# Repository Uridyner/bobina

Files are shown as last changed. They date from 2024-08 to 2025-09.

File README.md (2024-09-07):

# Bobina/Bob 3.0
Holis a todos, estos son los códigos de Bobina (también conocida como Bob 3.0)

Símbolo electrónico de un inductor
Símbolo electrónico de un inductor
Símbolo electrónico de un inductor
Símbolo electrónico de un inductor
Símbolo electrónico de un inductor
Símbolo electrónico de un inductor
Símbolo electrónico de un inductor
Símbolo electrónico de un inductor
Símbolo electrónico de un inductor
Símbolo electrónico de un inductor
Símbolo electrónico de un inductor
Símbolo electrónico de un inductor
Símbolo electrónico de un inductor
Símbolo electrónico de un inductor
Símbolo electrónico de un inductor
Símbolo electrónico de un inductor

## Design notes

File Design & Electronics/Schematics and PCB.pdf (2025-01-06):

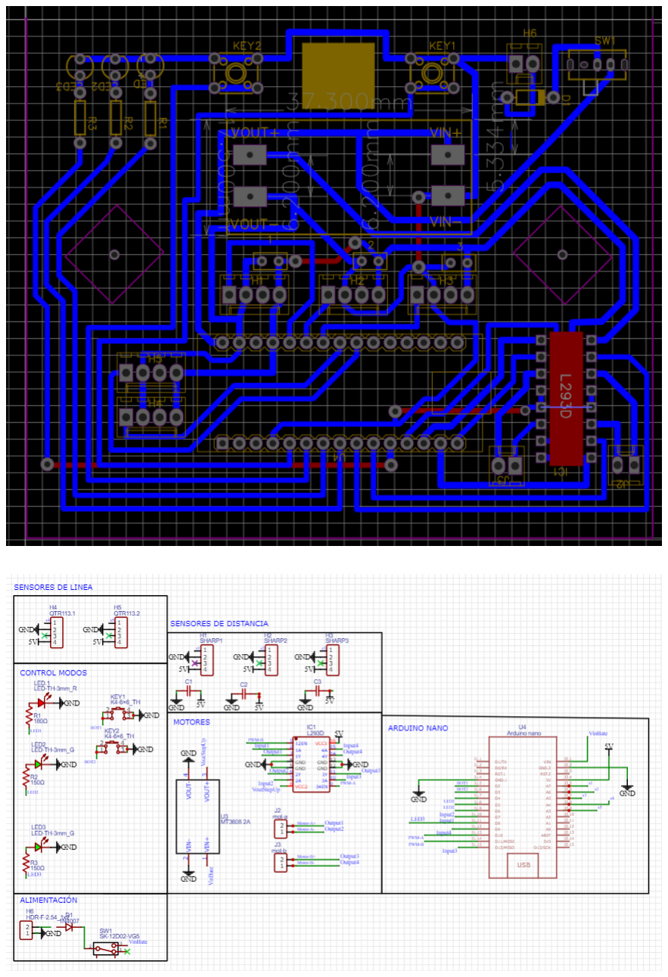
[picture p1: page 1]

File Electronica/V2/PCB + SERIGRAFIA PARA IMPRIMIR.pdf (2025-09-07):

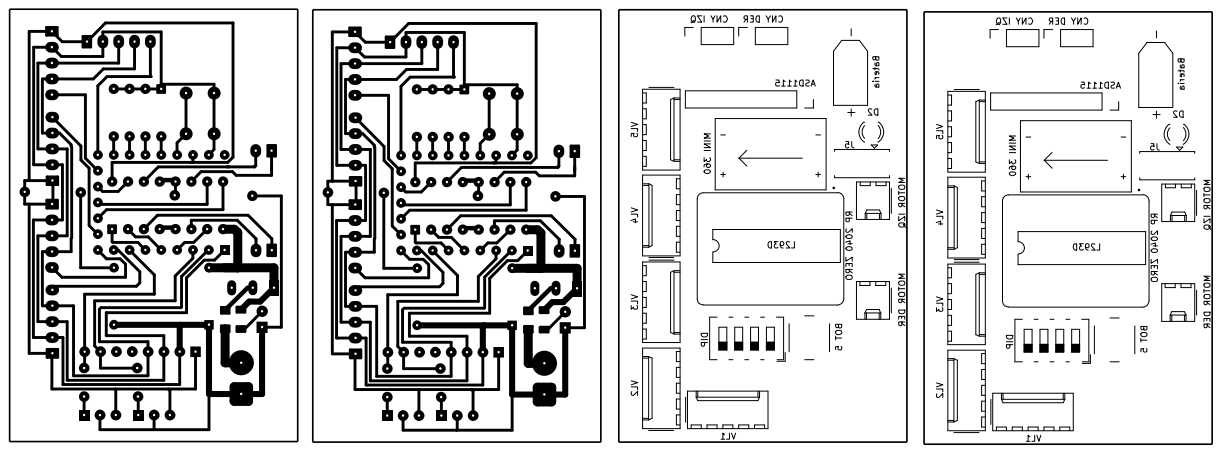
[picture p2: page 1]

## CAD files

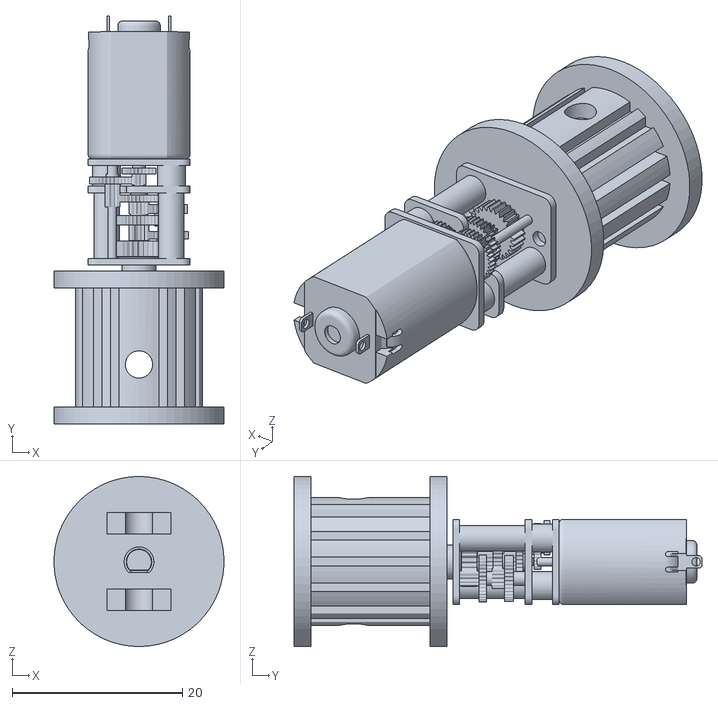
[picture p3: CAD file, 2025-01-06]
Design & Electronics/Wheel & Motor assembly.stl
20.0 x 48.0 x 20.0

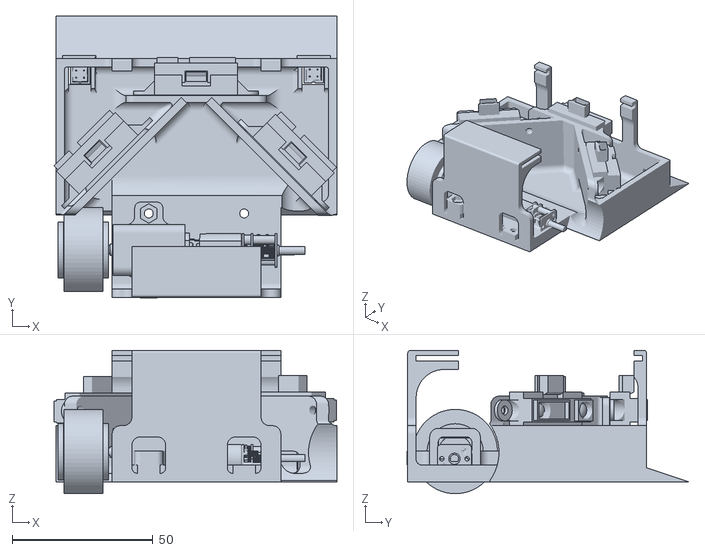
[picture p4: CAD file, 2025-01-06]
Design & Electronics/First bobina assembly.stl
100.7 x 100.2 x 51.0

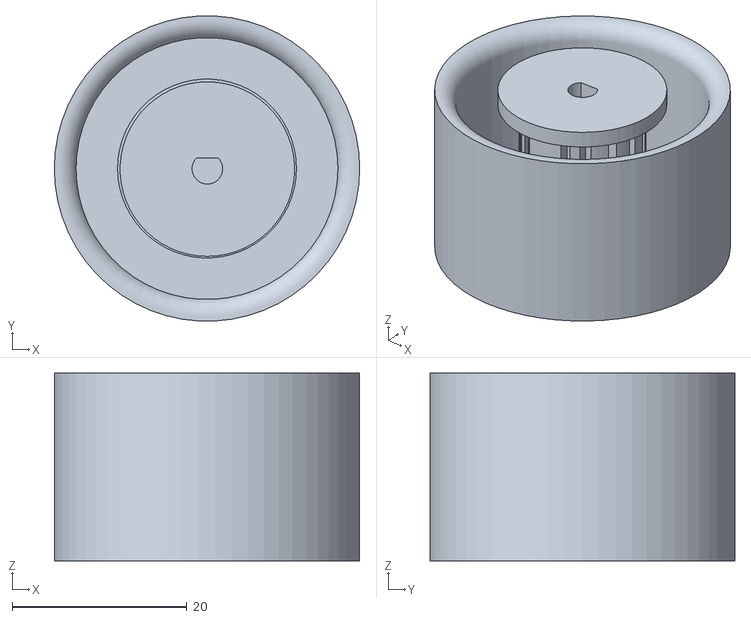
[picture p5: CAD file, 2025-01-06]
Design & Electronics/Mold & wheel assembly.stl
35.0 x 34.9 x 21.5

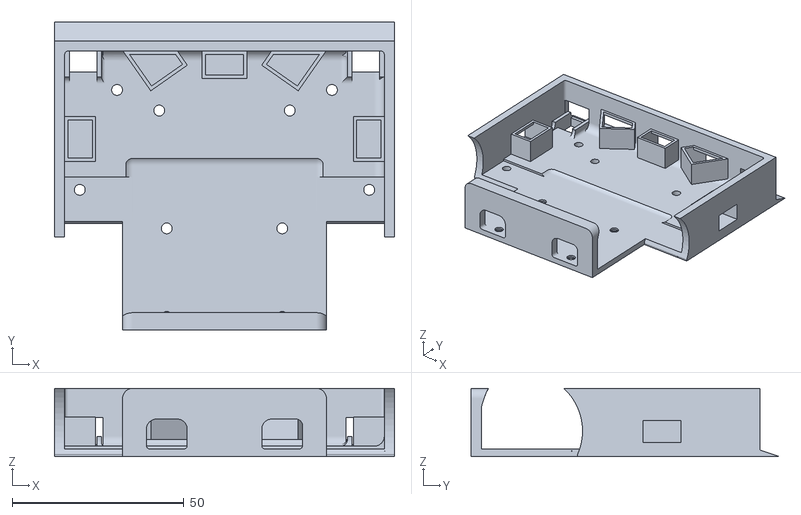
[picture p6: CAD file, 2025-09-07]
Design & Electronics/Nuevo Bobina V1.stl
99.0 x 89.6 x 19.8

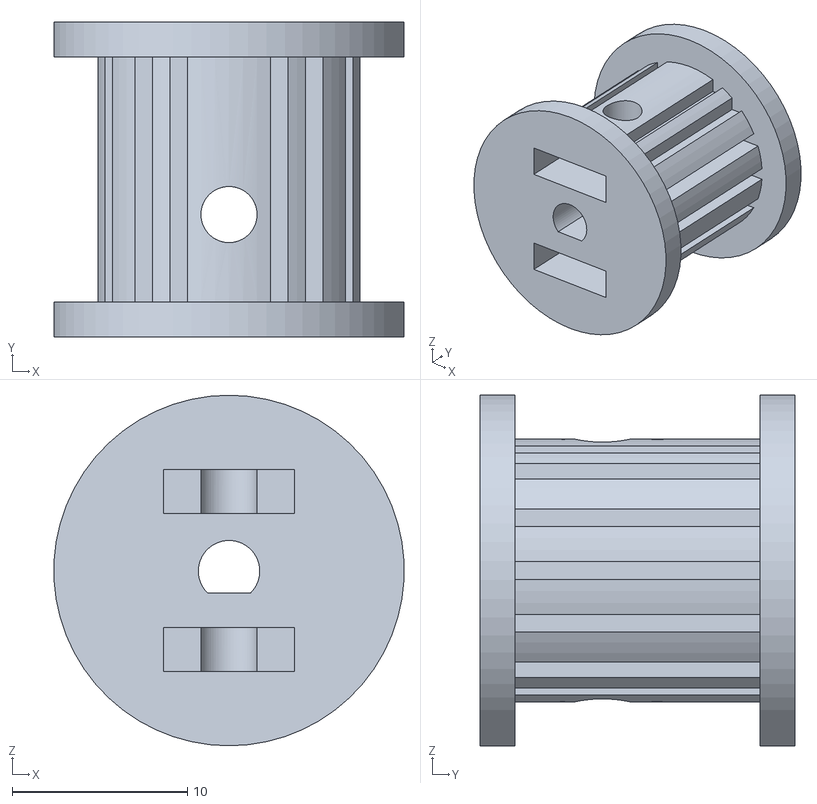
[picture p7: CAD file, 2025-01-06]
Design & Electronics/Wheel.stl
20.0 x 18.0 x 20.0

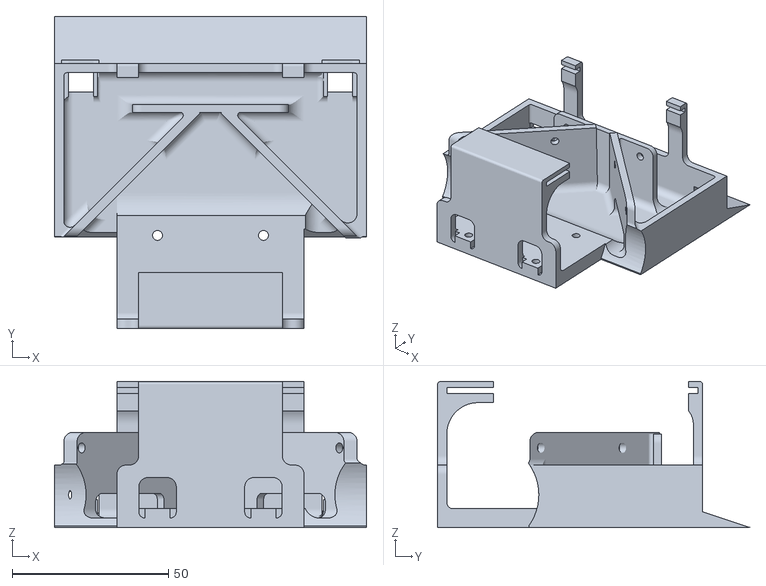
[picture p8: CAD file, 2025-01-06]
Design & Electronics/First Bobina.stl
100.0 x 100.0 x 46.8

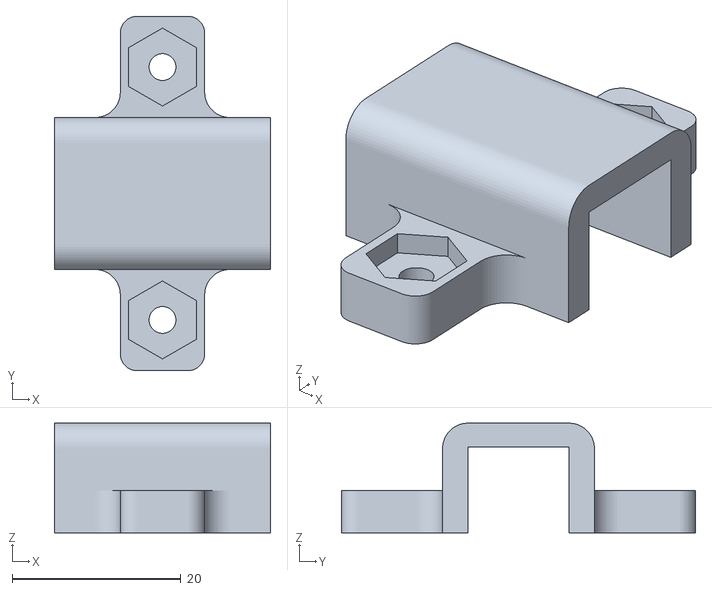
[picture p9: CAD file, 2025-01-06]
Design & Electronics/Motor holder.stl
25.6 x 42.0 x 13.0

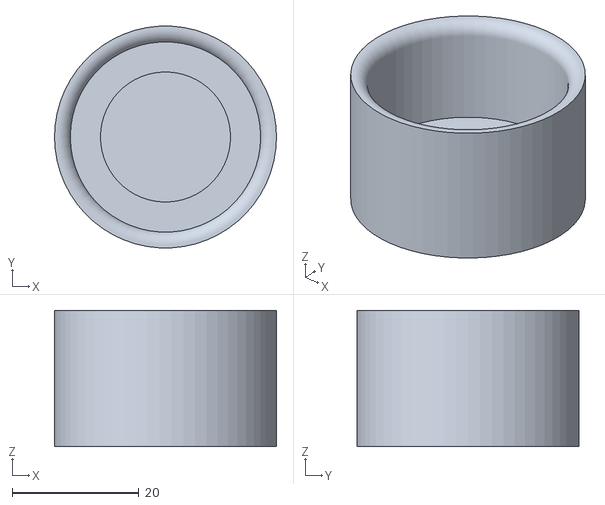
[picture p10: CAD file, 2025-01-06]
Design & Electronics/Mold.stl
35.0 x 34.9 x 21.5

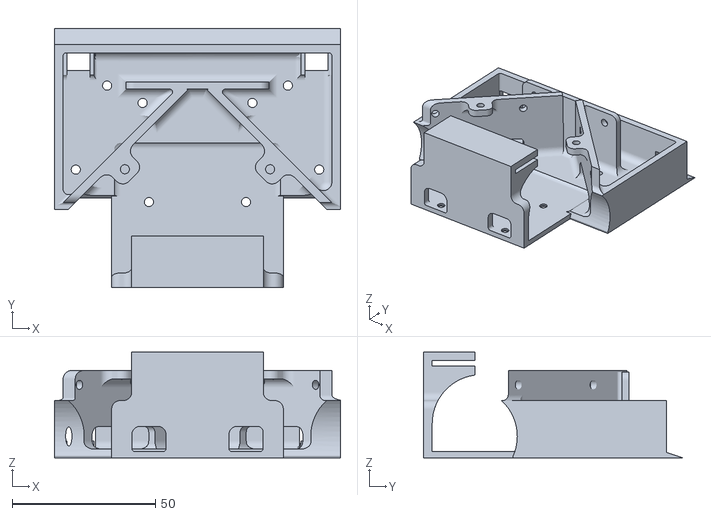
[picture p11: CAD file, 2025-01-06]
Design & Electronics/Last Bobina (for iron base).stl
100.0 x 90.5 x 37.0

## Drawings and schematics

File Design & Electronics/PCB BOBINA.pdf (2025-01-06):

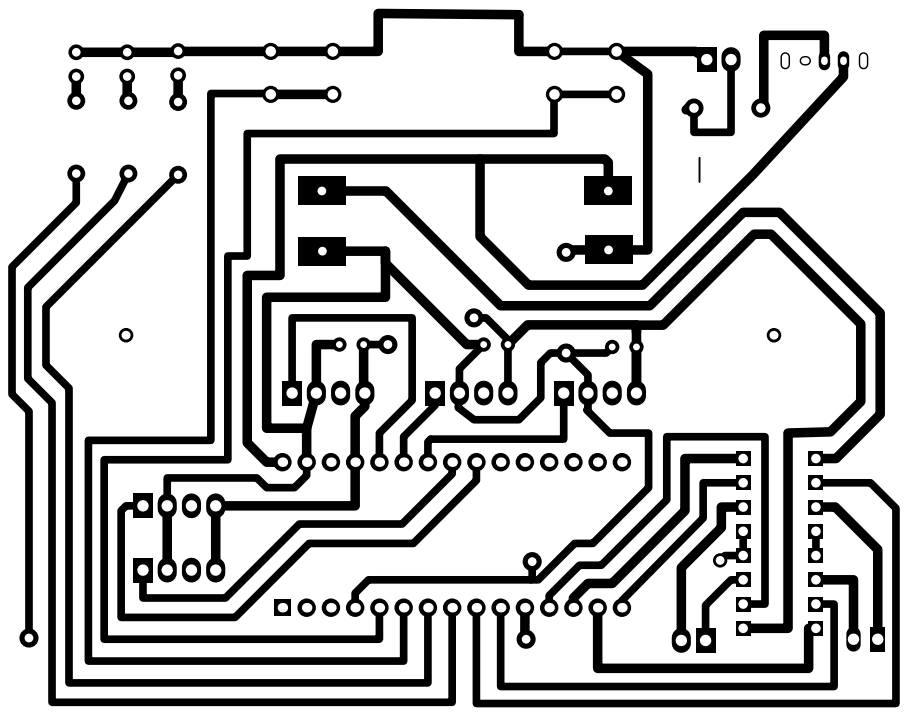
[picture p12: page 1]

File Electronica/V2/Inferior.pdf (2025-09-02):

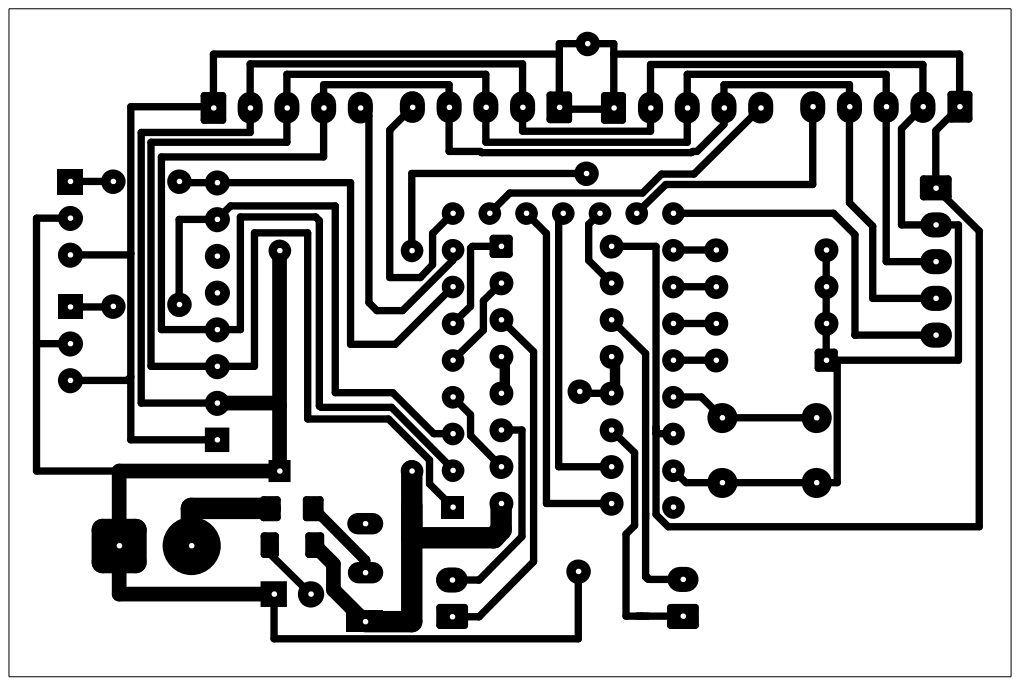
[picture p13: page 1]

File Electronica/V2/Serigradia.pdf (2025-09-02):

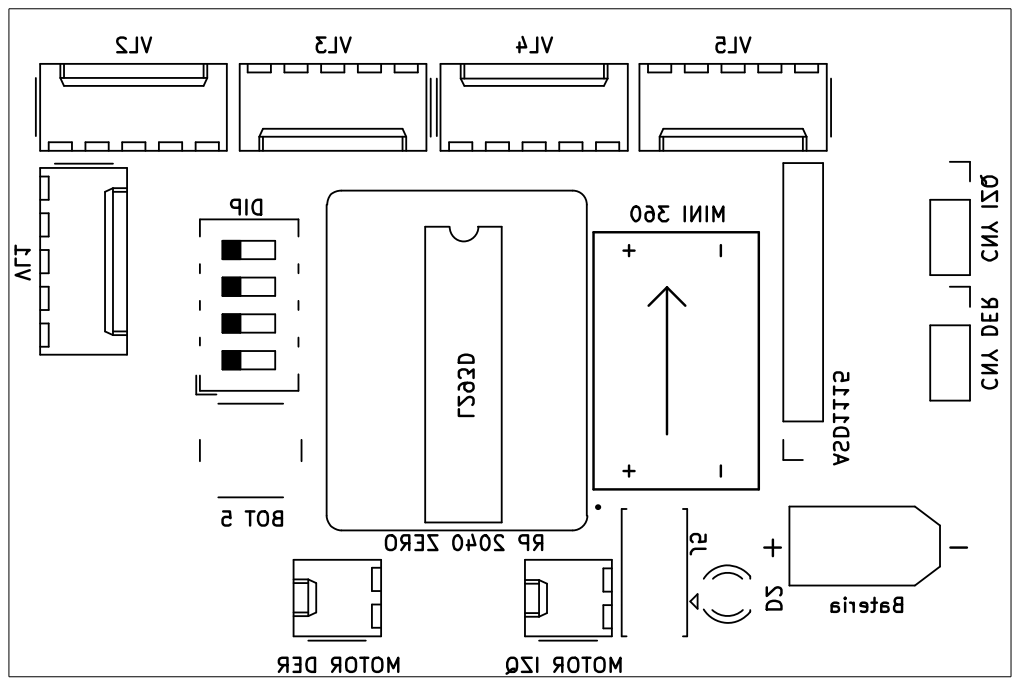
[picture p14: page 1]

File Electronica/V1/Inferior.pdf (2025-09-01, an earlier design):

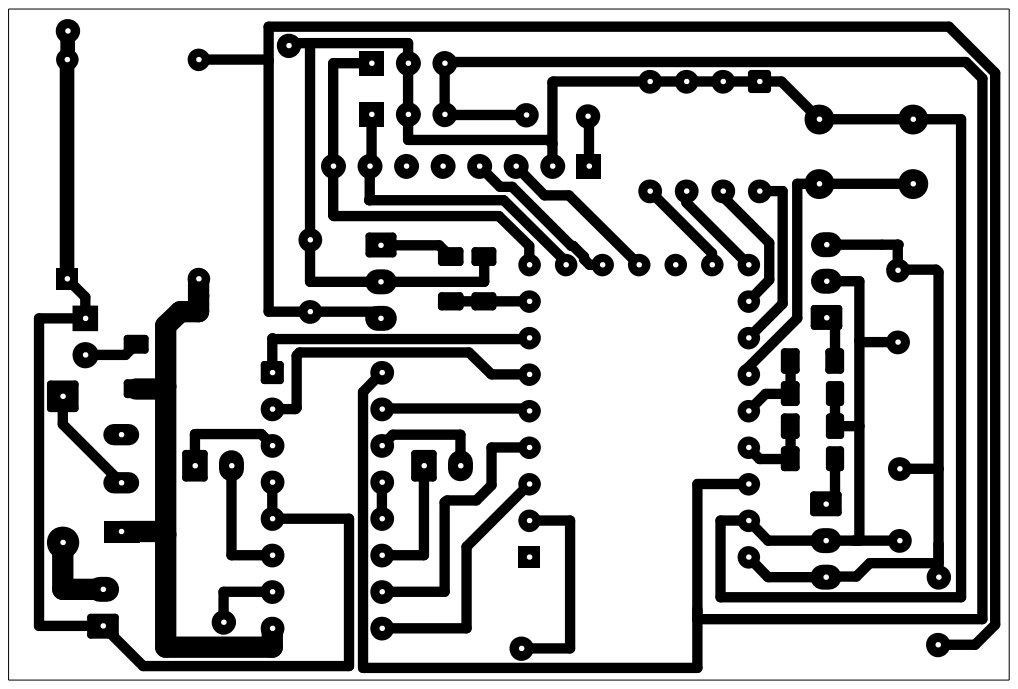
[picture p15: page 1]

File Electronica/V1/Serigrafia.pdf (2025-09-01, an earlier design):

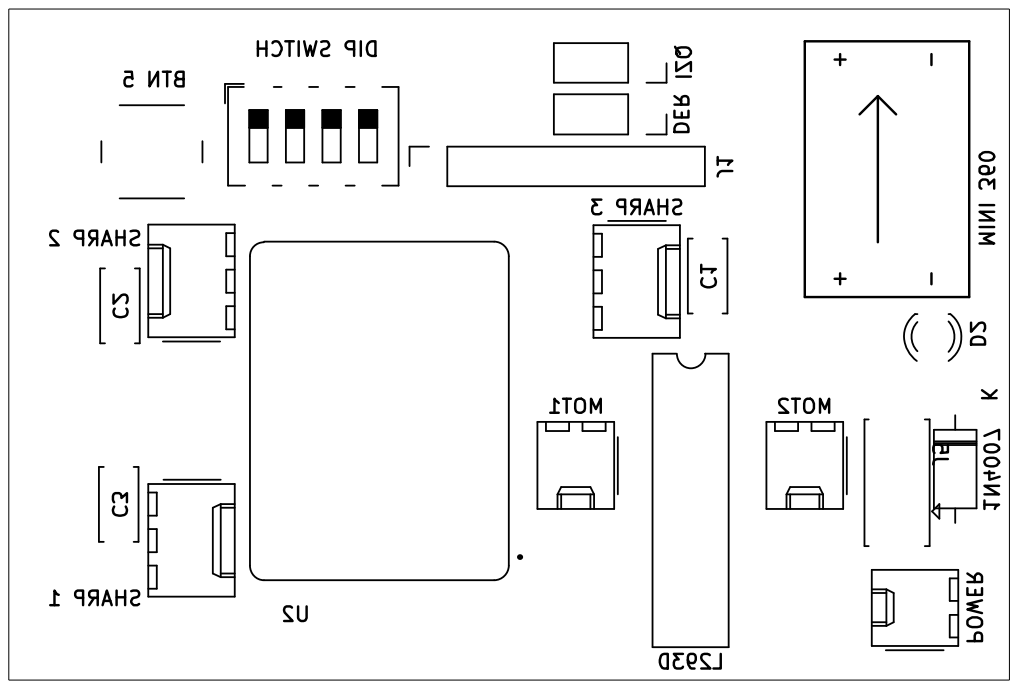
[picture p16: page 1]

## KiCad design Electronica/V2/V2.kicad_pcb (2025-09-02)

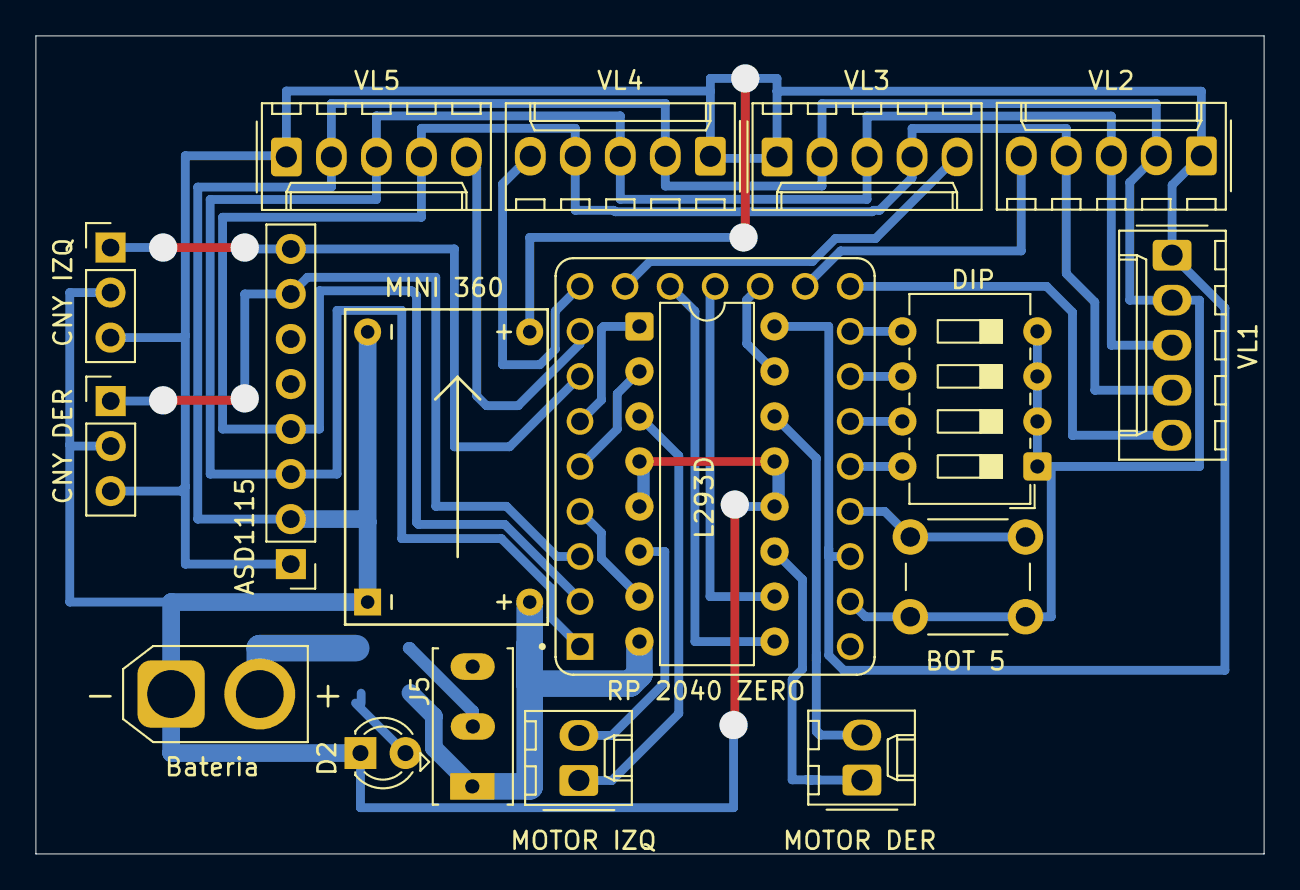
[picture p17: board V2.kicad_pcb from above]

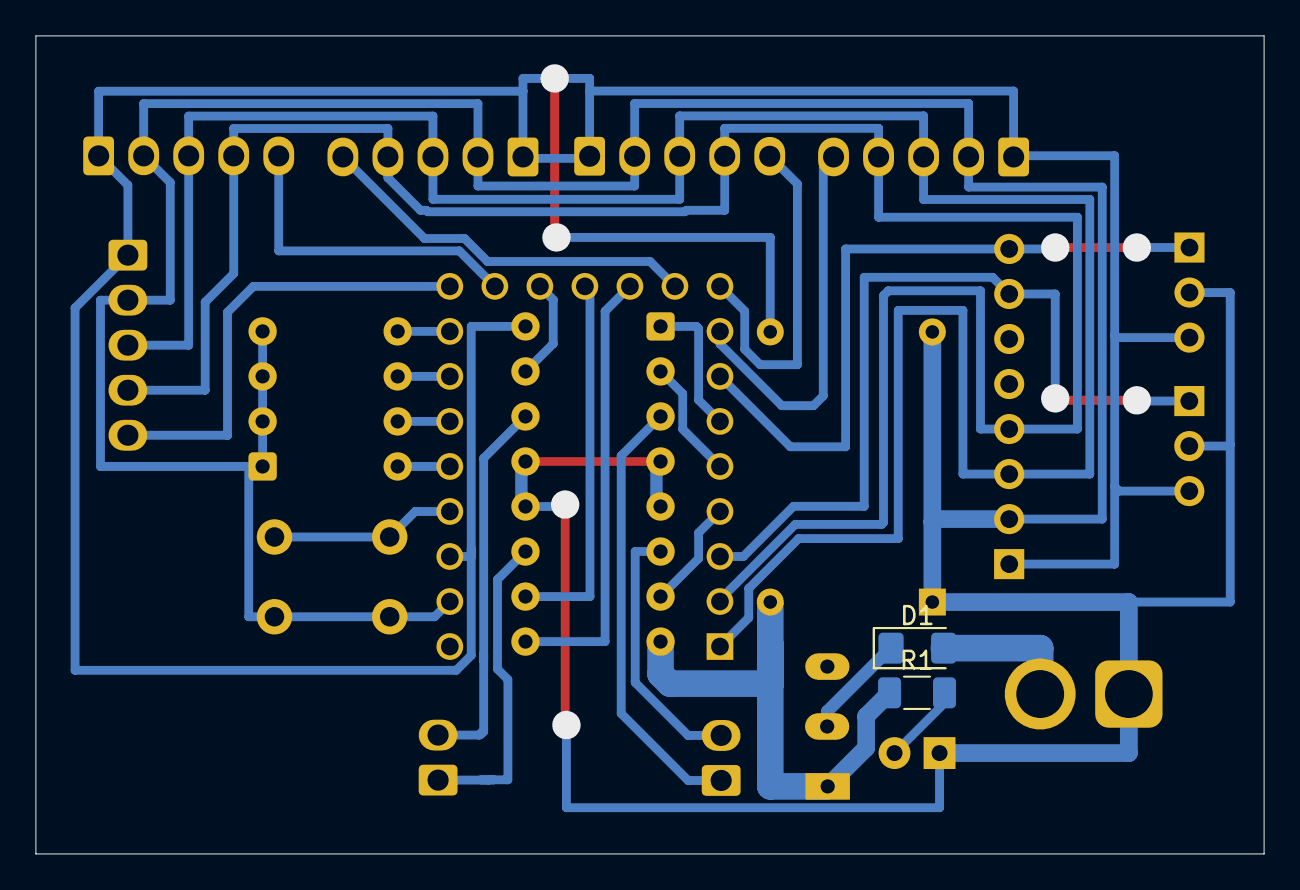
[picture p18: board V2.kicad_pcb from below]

Board: 2 copper layers, 69.3 x 46.2 mm, 20 parts (2 on the bottom side), 30 nets.

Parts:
ASD1115: Conn_01x08_Pin; PinHeader_1x08_P2.54mm_Vertical
BOT 5: SW_Push; SW_PUSH_6mm
Bateria: Power Input 1; AMASS_XT30U-F_1x02_P5.0mm_Vertical
CNY DER: Conn_01x03_Pin; PinHeader_1x03_P2.54mm_Vertical
CNY IZQ: Conn_01x03_Pin; PinHeader_1x03_P2.54mm_Vertical
D1: 1N4007; D_1206_3216Metric_Pad1.42x1.75mm_HandSolder
D2: LED; LED_D3.0mm_FlatTop
DIP: SW_DIP_x04; SW_DIP_SPSTx04_Slide_6.7x11.72mm_W7.62mm_P2.54mm_LowProfile
J5: On/Off General; SW_Slide_SPDT_Straight_CK_OS102011MS2Q
L293D: L293D; DIP-16_W7.62mm
MINI 360: Mini360_Module
MOTOR DER: Conn_01x02_Socket; Molex_KK-254_AE-6410-02A_1x02_P2.54mm_Vertical
MOTOR IZQ: Conn_01x02_Socket; Molex_KK-254_AE-6410-02A_1x02_P2.54mm_Vertical
R1: 220; R_1206_3216Metric_Pad1.30x1.75mm_HandSolder
RP 2040 ZERO: RP2040-ZERO; MODULE_RP2040-ZERO
VL1, VL2, VL3, VL4, VL5: Conn_01x05_Pin; Molex_KK-254_AE-6410-05A_1x05_P2.54mm_Vertical

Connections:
+3.3V: ASD1115.1, CNY DER.3, CNY IZQ.3, L293D.16 (VCC1), MINI 360.3 (OUT+), RP 2040 ZERO.21 (3V3), VL1.1, VL2.1, VL3.1, VL4.1, VL5.1
+12V: J5.1 (A), L293D.8 (VCC2), MINI 360.1 (IN+), R1.1
BOT1: DIP.8, RP 2040 ZERO.19 (GP28)
BOT2: DIP.7, RP 2040 ZERO.18 (GP27)
BOT3: DIP.6, RP 2040 ZERO.17 (GP26)
BOT4: DIP.5, RP 2040 ZERO.16 (GP15)
BOT5: BOT 5.2, RP 2040 ZERO.20 (GP29)
CNY_DER: ASD1115.7, CNY DER.1, RP 2040 ZERO.3 (GP2)
CNY_IZQ: ASD1115.8, CNY IZQ.1, RP 2040 ZERO.7 (GP6)
GND: ASD1115.2, BOT 5.1, Bateria.1, CNY DER.2, CNY IZQ.2, D2.1 (K), DIP.1, DIP.2, DIP.3, DIP.4, L293D.4 (GND), L293D.5 (GND), L293D.12 (GND), L293D.13 (GND), MINI 360.2 (IN-), MINI 360.4 (OUT-), RP 2040 ZERO.22 (GND), VL1.2, VL2.2, VL3.2, VL4.2, VL5.2
MOTORA1: L293D.2 (1A), RP 2040 ZERO.5 (GP4)
MOTORA2: L293D.7 (2A), RP 2040 ZERO.4 (GP3)
MOTORB1: L293D.10 (3A), RP 2040 ZERO.12 (GP11)
MOTORB2: L293D.15 (4A), RP 2040 ZERO.13 (GP12)
unnamed: Bateria.2, D1.2 (A)
unnamed: D1.1 (K), J5.2 (B)
unnamed: D2.2 (A), R1.2
unnamed: L293D.11 (3Y), MOTOR DER.1
unnamed: L293D.14 (4Y), MOTOR DER.2
unnamed: L293D.3 (1Y), MOTOR IZQ.1
unnamed: L293D.6 (2Y), MOTOR IZQ.2
PWMA: L293D.1 (EN1,2), RP 2040 ZERO.6 (GP5)
PWMB: L293D.9 (EN3,4), RP 2040 ZERO.11 (GP10)
SCL: ASD1115.3, RP 2040 ZERO.1 (GP0), VL1.3, VL2.3, VL3.3, VL4.3, VL5.3
SDA: ASD1115.4, RP 2040 ZERO.2 (GP1), VL1.4, VL2.4, VL3.4, VL4.4, VL5.4
VL1: RP 2040 ZERO.15 (GP14), VL1.5
VL2: RP 2040 ZERO.14 (GP13), VL2.5
VL3: RP 2040 ZERO.10 (GP9), VL3.5
VL4: RP 2040 ZERO.9 (GP8), VL4.5
VL5: RP 2040 ZERO.8 (GP7), VL5.5

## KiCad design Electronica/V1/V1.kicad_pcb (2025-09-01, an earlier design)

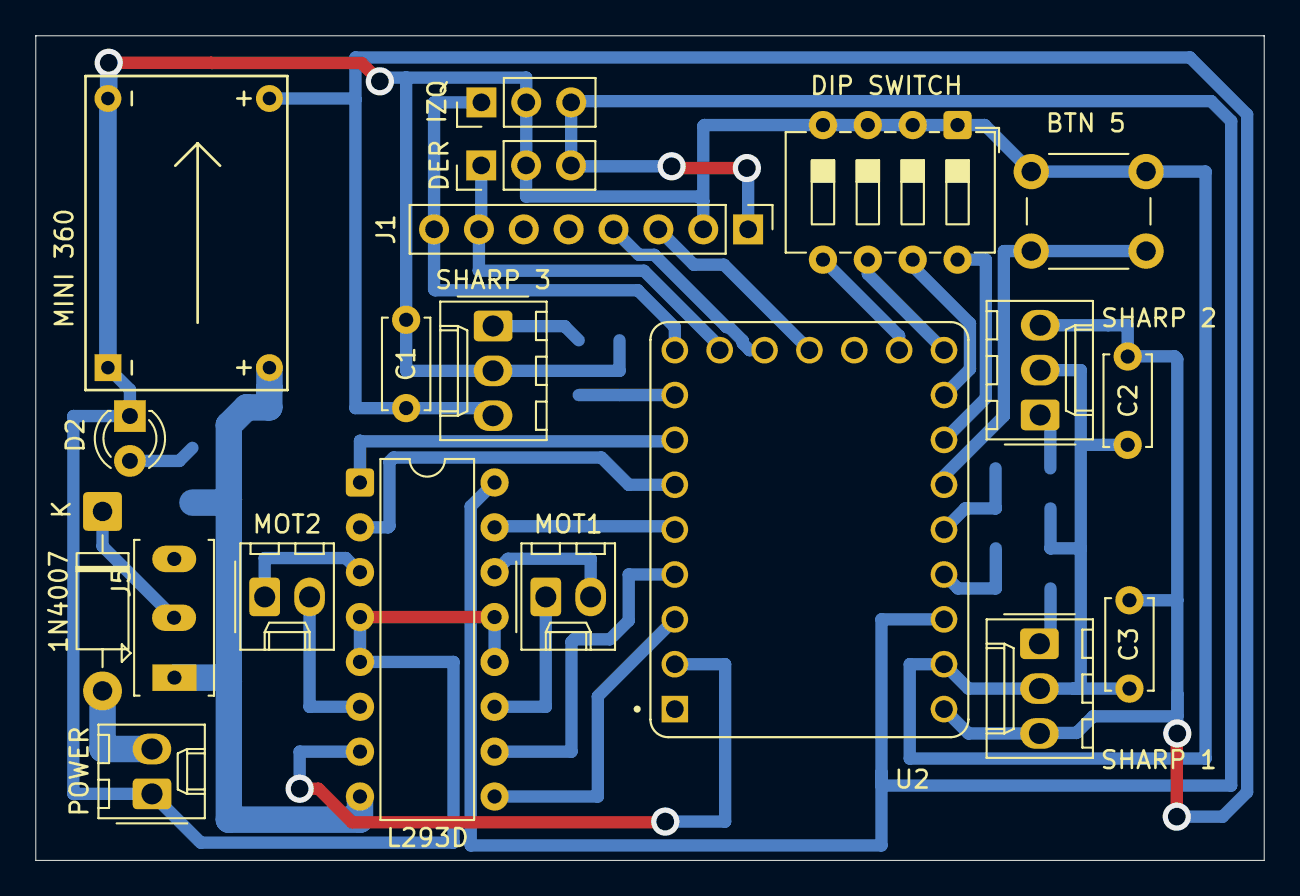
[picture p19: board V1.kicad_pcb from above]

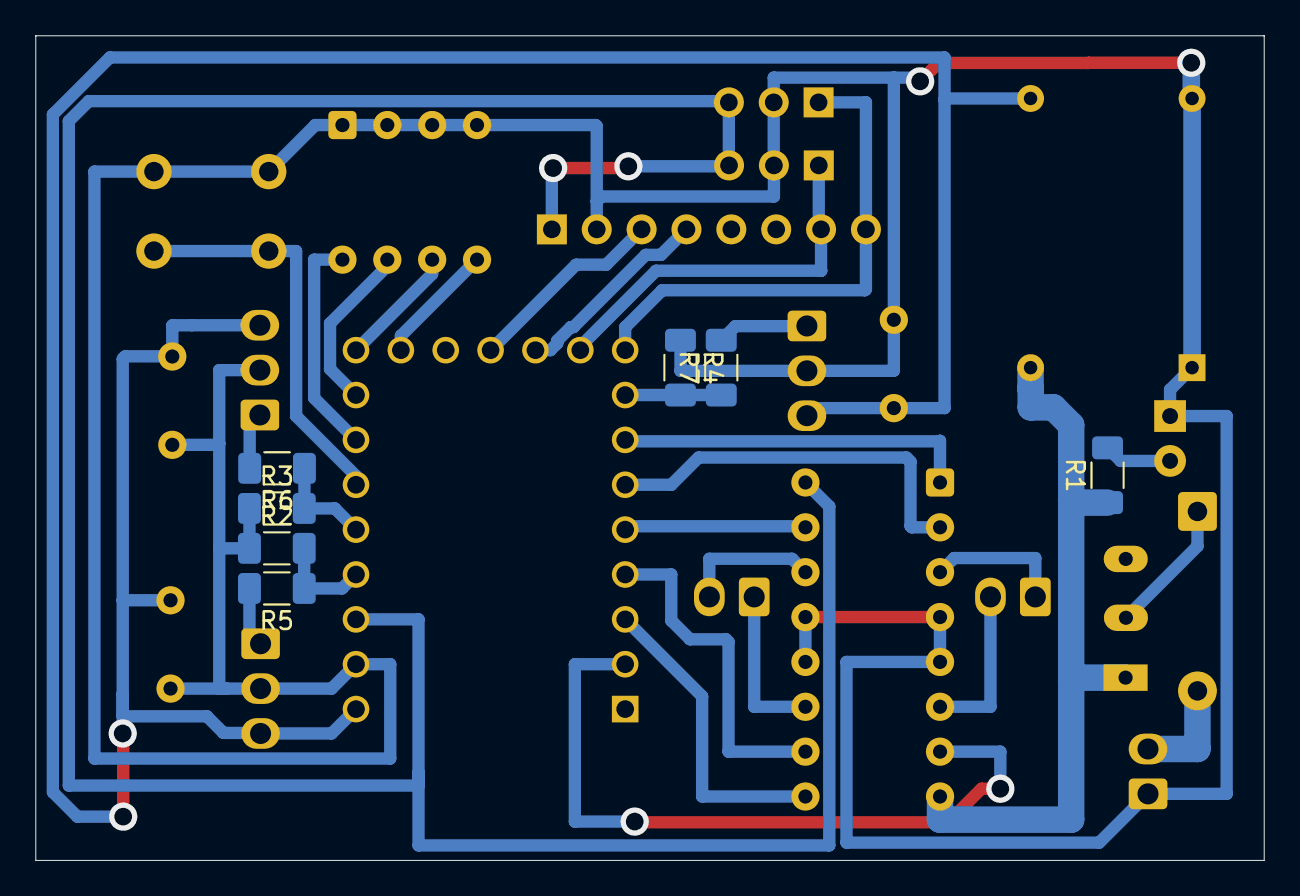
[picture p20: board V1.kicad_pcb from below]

Board: 2 copper layers, 69.6 x 46.7 mm, 27 parts (7 on the bottom side), 32 nets.

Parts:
1N4007: 1N4007; D_DO-41_SOD81_P10.16mm_Horizontal
BTN 5: SW_Push; SW_PUSH_6mm
C1, C2, C3: C_Small; C_Disc_D5.0mm_W2.5mm_P5.00mm
D2: LED; LED_D3.0mm_FlatTop
DER: Conn_01x03_Pin; PinHeader_1x03_P2.54mm_Vertical
DIP SWITCH: SW_DIP_x04; SW_DIP_SPSTx04_Slide_6.7x11.72mm_W7.62mm_P2.54mm_LowProfile
IZQ: Conn_01x03_Pin; PinHeader_1x03_P2.54mm_Vertical
J1: Conn_01x08_Pin; PinHeader_1x08_P2.54mm_Vertical
J5: On/Off General; SW_Slide_SPDT_Straight_CK_OS102011MS2Q
L293D: L293D; DIP-16_W7.62mm
MINI 360: Mini360_Module
MOT1, MOT2: Conn_01x02_Socket; Molex_KK-254_AE-6410-02A_1x02_P2.54mm_Vertical
POWER: Power Input 1; Molex_KK-254_AE-6410-02A_1x02_P2.54mm_Vertical
R1: 220; R_1206_3216Metric_Pad1.30x1.75mm_HandSolder
R2, R3, R4, R5, R6, R7: R; R_1206_3216Metric_Pad1.30x1.75mm_HandSolder
SHARP 1, SHARP 2, SHARP 3: Conn_01x03_Pin; Molex_KK-254_AE-6410-03A_1x03_P2.54mm_Vertical
U2: RP2040-ZERO; MODULE_RP2040-ZERO

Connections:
+3.3V: DER.3, IZQ.3, J1.1, L293D.16 (VCC1), U2.21 (3V3)
+5V: C1.2, C2.2, C3.2, MINI 360.3 (OUT+), SHARP 1.3, SHARP 2.3, SHARP 3.3, U2.23 (5V)
+12V: J5.1 (A), L293D.8 (VCC2), MINI 360.1 (IN+), R1.1
BOT1: DIP SWITCH.8, U2.17 (GP26)
BOT2: DIP SWITCH.7, U2.16 (GP15)
BOT3: DIP SWITCH.6, U2.15 (GP14)
BOT4: DIP SWITCH.5, U2.14 (GP13)
BOT5: BTN 5.2, U2.18 (GP27)
CNY_DER: DER.1, J1.7, U2.10 (GP9)
CNY_IZQ: IZQ.1, J1.8, U2.9 (GP8)
GND: BTN 5.1, C1.1, C2.1, C3.1, D2.1 (K), DER.2, DIP SWITCH.1, DIP SWITCH.2, DIP SWITCH.3, DIP SWITCH.4, IZQ.2, J1.2, L293D.4 (GND), L293D.5 (GND), L293D.12 (GND), L293D.13 (GND), MINI 360.2 (IN-), MINI 360.4 (OUT-), POWER.1, R2.1, R3.1, R4.1, SHARP 1.2, SHARP 2.2, SHARP 3.2, U2.22 (GND)
MOTORA1: L293D.2 (1A), U2.6 (GP5)
MOTORA2: L293D.7 (2A), U2.2 (GP1)
MOTORB1: L293D.10 (3A), U2.4 (GP3)
MOTORB2: L293D.15 (4A), U2.5 (GP4)
unnamed: 1N4007.2 (A), POWER.2
unnamed: 1N4007.1 (K), J5.2 (B)
unnamed: D2.2 (A), R1.2
unnamed: L293D.11 (3Y), MOT1.1
unnamed: L293D.14 (4Y), MOT1.2
unnamed: L293D.3 (1Y), MOT2.1
unnamed: L293D.6 (2Y), MOT2.2
PWMA: L293D.1 (EN1,2), U2.7 (GP6)
PWMB: L293D.9 (EN3,4), U2.3 (GP2)
Pin_Sharp_1: R2.2, R5.1, U2.20 (GP29)
Pin_Sharp_2: R3.2, R6.1, U2.19 (GP28)
Pin_Sharp_3: R4.2, R7.1, U2.8 (GP7)
SCL: J1.3, U2.12 (GP11)
SDA: J1.4, U2.11 (GP10)
Sharp1: R5.2, SHARP 1.1
Sharp2: R6.2, SHARP 2.1
Sharp3: R7.2, SHARP 3.1

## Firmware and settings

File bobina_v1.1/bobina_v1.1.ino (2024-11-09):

#include <Smoothed.h>

/// Motor izquierdo, adelante
constexpr uint8_t MOT_L_A = 7;
/// Motor izquierdo, atrás
constexpr uint8_t MOT_L_B = 6;
/// Motor izquierdo, velocidad/PWM
constexpr uint8_t MOT_L_PWM = 11;
/// Motor izquierdo, velocidad/PWM máximo
constexpr uint8_t MOT_L_PWM_MAX = 130;
/// Motor derecho, adelante
constexpr uint8_t MOT_R_A = 9;
/// Motor derecho, atrás
constexpr uint8_t MOT_R_B = 12;
/// Motor derecho, velocidad/PWM
constexpr uint8_t MOT_R_PWM = 10;
/// Motor derecho, velocidad/PWM máximo
constexpr uint8_t MOT_R_PWM_MAX = 130;

enum LadoSharp {
  SHARP_IZQ = 0,
  SHARP_CEN = 1,
  SHARP_DER = 2,
};
/// Pines de los sharps
constexpr uint8_t PINES_SHARPS[] = { A7, A6, A5 };
/// Numero de sharps en la placa
constexpr size_t NUM_SHARPS = sizeof(PINES_SHARPS) / sizeof(PINES_SHARPS[0]);
/// Cantidad de veces que se leen los sharps.
///
/// Se usa para tomar un promedio de las lecturas y limpiar los valores.
constexpr size_t LECTURAS_SHARP = 2;
/// Lecturas por segundos de los sharp
constexpr unsigned long FRECUENCIA_LECTURA_SHARP = 25;

enum LadoCNY {
  CNY_IZQ = 0,
  CNY_DER = 1,
};
/// Pines de los CNYs
constexpr uint8_t PINES_CNY[] = { A3, A4 };
/// Numero de CNYs en la placa
constexpr size_t NUM_CNY = sizeof(PINES_CNY) / sizeof(PINES_SHARPS[0]);
/// Cantidad de veces que se leen los CNYs.
///
/// Se usa para tomar un promedio de las lecturas y limpiar los valores.
constexpr size_t LECTURAS_CNY = 3;

/// Voltaje máximo del ADC
constexpr float VOLTAJE_MAX_ADC = 5.0;
/// Bits que tiene el ADC
constexpr uint8_t BITS_ADC = 10;
/// Valor máximo del ADC
constexpr uint16_t VALOR_MAX_ADC = 1024;
/// Convertir lectura a voltaje
constexpr float lecturaAVoltaje(uint16_t lectura) {
  return ((float)lectura * VOLTAJE_MAX_ADC) / (float)VALOR_MAX_ADC;
}
/// Convertir voltaje a lectura
constexpr uint16_t voltajeALectura(float voltaje) {
  return (uint16_t)((voltaje * (float)VALOR_MAX_ADC) / VOLTAJE_MAX_ADC);
}

/// Pines de los LEDs
constexpr uint8_t PINES_LEDS[] = { 8, 5, 4 };
/// Numero de LEDs en la placa
constexpr size_t NUM_LEDS = sizeof(PINES_LEDS) / sizeof(PINES_LEDS[0]);

/// Pines de los botones
constexpr uint8_t PINES_BOTONES[] = { 3, 2 };
/// Numero de botones en la placa
constexpr size_t NUM_BOTONES = sizeof(PINES_BOTONES) / sizeof(PINES_BOTONES[0]);

/// Tiempo que se espera antes de empezar a correr
constexpr unsigned int TIEMPO_ESPERA_MS = 5000;

/// Tiempo que retrocede cuando detecta que está sobre el borde
constexpr unsigned int TIEMPO_RETROCEDER_MS = 200;

/// Tiempo que se espera antes de avanzar forzadamente para evitar que se pare la pelea
constexpr unsigned int TIEMPO_ESPERA_AVANCE_FORZADO_MS = 500;

/// Tiempo que avanza forzadamente para evitar que se pare la pelea
constexpr unsigned int TIEMPO_AVANCE_FORZADO_MS = 350;

// #define DEBUG 1

#if DEBUG
#define debugSetup() Serial.begin(115200)
#define debugPrint(texto) Serial.print(texto)
#define debugPrintln(texto) Serial.println(texto)
#else
#define debugSetup()
#define debugSetup(baudios)
#define debugPrint(texto)
#define debugPrintln(texto)
#endif

void adelante() {
  debugPrintln("Adelante");
  digitalWrite(MOT_L_A, HIGH);
  digitalWrite(MOT_L_B, LOW);
  digitalWrite(MOT_R_A, HIGH);
  digitalWrite(MOT_R_B, LOW);
}

void atras() {
  debugPrintln("Atras");
  digitalWrite(MOT_L_A, LOW);
  digitalWrite(MOT_L_B, HIGH);
  digitalWrite(MOT_R_A, LOW);
  digitalWrite(MOT_R_B, HIGH);
}

void izquierda() {
  debugPrintln("Izquierda");
  digitalWrite(MOT_L_A, HIGH);
  digitalWrite(MOT_L_B, LOW);
  digitalWrite(MOT_R_A, LOW);
  digitalWrite(MOT_R_B, HIGH);
}

void derecha() {
  debugPrintln("Derecha");
  digitalWrite(MOT_L_A, LOW);
  digitalWrite(MOT_L_B, HIGH);
  digitalWrite(MOT_R_A, HIGH);
  digitalWrite(MOT_R_B, LOW);
}

void parada() {
  debugPrintln("Parada");
  digitalWrite(MOT_L_A, LOW);
  digitalWrite(MOT_L_B, LOW);
  digitalWrite(MOT_R_A, LOW);
  digitalWrite(MOT_R_B, LOW);
}

void frenar() {
  debugPrintln("Frenado");
  digitalWrite(MOT_L_A, HIGH);
  digitalWrite(MOT_L_B, HIGH);
  digitalWrite(MOT_R_A, HIGH);
  digitalWrite(MOT_R_B, HIGH);
}

void setupMotores() {
  debugPrintln("Inicializando pines de los motores...");
  debugPrintln("Pin motor izq adelante");
  pinMode(MOT_L_A, OUTPUT);
  debugPrintln("Pin motor izq atras");
  pinMode(MOT_L_B, OUTPUT);
  debugPrintln("Pin motor izq velocidad (PWM)");
  pinMode(MOT_L_PWM, OUTPUT);
  debugPrintln("Pin motor der adelante");
  pinMode(MOT_R_A, OUTPUT);
  debugPrintln("Pin motor der atras");
  pinMode(MOT_R_B, OUTPUT);
  debugPrintln("Pin motor der velocidad (PWM)");
  pinMode(MOT_R_PWM, OUTPUT);
  debugPrintln("Pines de los motores inicializados!");

  debugPrintln("Poniendo dirección inicial en los motores");
  frenar();
  debugPrintln("Puesta la dirección inicial en los motores!");

  debugPrintln("Poniendo velocidad en los motores");
  analogWrite(MOT_L_PWM, MOT_L_PWM_MAX);
  analogWrite(MOT_R_PWM, MOT_R_PWM_MAX);
  debugPrintln("Velocidad de los motores establecidas!");
}

unsigned long activacionesSharp[NUM_SHARPS] = { 55, 55, 55 };
Smoothed<uint16_t> smoothedSharps[NUM_SHARPS];
unsigned long ultimaLecturaSharps = -1;

Smoothed<uint16_t>* leerSharps() {
  if (millis() - ultimaLecturaSharps >= 1000 / FRECUENCIA_LECTURA_SHARP) {
    ultimaLecturaSharps = millis();
    for (size_t i = 0; i < NUM_SHARPS; i++) {
      uint16_t lectura = analogRead(PINES_SHARPS[i]);
      smoothedSharps[i].add(lectura);
      debugPrint("Sharp");
      debugPrint(i + 1);
      debugPrint(':');
      debugPrint(lectura);
      debugPrint('\t');
    }
    debugPrintln();
    ultimaLecturaSharps = millis();
  }
  return smoothedSharps;
}

void setupSharps() {
  debugPrintln("Inicializando pines de los sharps...");
  for (int i = 0; i < NUM_SHARPS; i++) {
    debugPrint("Sensor distancia sharp ");
    pinMode(PINES_SHARPS[i], INPUT);
    smoothedSharps[i].begin(SMOOTHED_AVERAGE, LECTURAS_SHARP);
    debugPrintln(i + 1);
  }
  debugPrintln("Pines de los sharps inicializados!");
}

float activacionesCNY[NUM_CNY] = { 0, 0 };
float lecturasCNY[NUM_CNY];

float* leerCNY() {
  for (size_t i = 0; i < NUM_CNY; i++) {
    lecturasCNY[i] = 0;
    for (size_t j = 0; j < LECTURAS_CNY; j++) {
      lecturasCNY[i] += lecturaAVoltaje(analogRead(PINES_CNY[i])) / LECTURAS_CNY;
    }
    debugPrint("CNY");
    debugPrint(i + 1);
    debugPrint(':');
    debugPrint(lecturasCNY[i]);
    debugPrint('\t');
  }
  debugPrintln();
  return lecturasCNY;
}

void setupCNY() {
  debugPrintln("Inicializando pines de los CNYs...");
  for (int i = 0; i < NUM_CNY; i++) {
    debugPrint("Sensor piso CNY ");
    pinMode(PINES_CNY[i], INPUT);
    debugPrintln(i + 1);
  }
  debugPrintln("Pines de los CNYs inicializados!");
}

void setupLeds() {
  debugPrintln("Inicializando pines de los leds...");
  for (int i = 0; i < NUM_LEDS; i++) {
    debugPrint("Led ");
    pinMode(PINES_LEDS[i], OUTPUT);
    debugPrintln(i + 1);
  }
  debugPrintln("Pines de los leds inicializados!");
}

inline void cambiarLed(size_t led, bool estado) {
  digitalWrite(PINES_LEDS[led], estado);
}

void setupBotones() {
  debugPrintln("Inicializando pines de los botones...");
  for (int i = 0; i < NUM_BOTONES; i++) {
    debugPrint("Boton ");
    pinMode(PINES_BOTONES[i], INPUT_PULLUP);
    debugPrintln(i + 1);
  }
  debugPrintln("Pines de los botones inicializados!");
}

inline bool estaPresionado(size_t boton) {
  bool valor = digitalRead(PINES_BOTONES[boton]);
  debugPrint("Boton ");
  debugPrint(boton);
  debugPrint(": ");
  debugPrintln(valor);
  return valor == LOW;
}

enum {
  BASICA_DER,
  BASICA_IZQ,
  PASITOS,
  // PRUEBA1,
  // PRUEBA2,
  // PRUEBA3,
  // PRUEBA4,
  // PRUEBA5,
  // PRUEBA6,
  // PRUEBA7,
  // PRUEBA8,
  // PRUEBA9,
  // PRUEBA10,
  // PRUEBA11,
  // PRUEBA12,
  // PRUEBA13,
  // PRUEBA14,
  // PRUEBA15,
  // PRUEBA16,
  // PRUEBA17,
  // PRUEBA18,
  // PRUEBA19,
  // PRUEBA20,
  // PRUEBA21,
  // PRUEBA22,
  // PRUEBA23,
  // PRUEBA24,
  NUM_ESTRATEGIAS,
} estrategia;

void setup() {
  debugSetup();

  for (size_t i = 0; i < NUM_LEDS - 1; i++) {
    cambiarLed(i, bitRead(0, i));
  }
  setupMotores();

  for (size_t i = 0; i < NUM_LEDS - 1; i++) {
    cambiarLed(i, bitRead(1, i));
  }
  setupSharps();

  for (size_t i = 0; i < NUM_LEDS - 1; i++) {
    cambiarLed(i, bitRead(2, i));
  }
  setupLeds();

  for (size_t i = 0; i < NUM_LEDS - 1; i++) {
    cambiarLed(i, bitRead(3, i));
  }
  setupCNY();

  for (size_t i = 0; i < NUM_LEDS - 1; i++) {
    cambiarLed(i, bitRead(4, i));
  }
  setupBotones();

  unsigned long ultimoCambioLeds = millis();
  unsigned long comienzoPresionBoton0 = millis();
  unsigned long comienzoPresionBoton1 = millis();
  bool ultimoEstadoBoton0 = estaPresionado(0);
  bool ultimoEstadoBoton1 = estaPresionado(1);

  while (true) {
    for (size_t i = 0; i < NUM_LEDS; i++) {
      unsigned char valor = (estrategia / (int)pow(3, NUM_LEDS - i - 1)) % 3;
      if (valor == 0) {
        cambiarLed(i, false);
      } else if (valor == 1) {
        cambiarLed(i, ((millis() + i * 100) % 400) < 100);
      } else if (valor == 2) {
        cambiarLed(i, true);
      }
    }
    bool estadoBoton0 = estaPresionado(0);
    bool estadoBoton1 = estaPresionado(1);
    if (estadoBoton0 == true && ultimoEstadoBoton0 == false) {
      comienzoPresionBoton0 = millis();
    } else if (estadoBoton0 == false && ultimoEstadoBoton0 == true && millis() - comienzoPresionBoton0 > 100) {
      estrategia = estrategia + 1;
      estrategia %= NUM_ESTRATEGIAS;
    }
    if (estadoBoton1 == true && ultimoEstadoBoton1 == false) {
      comienzoPresionBoton1 = millis();
    } else if (estadoBoton1 == false && ultimoEstadoBoton1 == true && millis() - comienzoPresionBoton1 > 100) {
      break;
    }
    ultimoEstadoBoton0 = estadoBoton0;
    ultimoEstadoBoton1 = estadoBoton1;
  }

  for (size_t i = 0; i < NUM_LEDS - 1; i++) {
    cambiarLed(i, true);
  }

  // Esperar a que se suelte
  while (estaPresionado(0) == false) {}

  // Esperar a que se aprete
  while (estaPresionado(1) == true) {}

  unsigned long tiempoComienzo = millis();

#if DEBUG
  unsigned char ultimoDigitoTiempoAnterior = -1;
#endif

  unsigned long ultimaLecturaCNYs = millis();
  unsigned int numeroLecturasCNYs = 1;
  unsigned long ultimaLecturaSharps = millis();
  unsigned int numeroLecturasSharps = 1;

  while (millis() - tiempoComienzo < TIEMPO_ESPERA_MS) {
    unsigned long segundosRestantes = (TIEMPO_ESPERA_MS - (millis() - tiempoComienzo)) / 1000;

    for (size_t i = 0; i < NUM_LEDS; i++) {
      cambiarLed(i, bitRead(segundosRestantes, i) == true);
    }

    if (millis() - ultimaLecturaCNYs > 20) {
      leerCNY();
      for (size_t i = 0; i < NUM_CNY; i++) {
        activacionesCNY[i] += lecturasCNY[i];
      }
      ultimaLecturaCNYs = millis();
      numeroLecturasCNYs++;
    }

    if (millis() - ultimaLecturaSharps > 40 && segundosRestantes <= 2) {
      for (size_t i = 0; i < NUM_SHARPS; i++) {
        unsigned long lectura = analogRead(PINES_SHARPS[i]);
        activacionesSharp[i] += lectura;
        debugPrint("Sharp");
        debugPrint(i + 1);
        debugPrint(':');
        debugPrint(lectura);
        debugPrint('\t');
      }
      debugPrintln();
      ultimaLecturaSharps = millis();
      numeroLecturasSharps++;
    }
  }

  debugPrintln("Activaciones CNYs");
  for (size_t i = 0; i < NUM_CNY; i++) {
    activacionesCNY[i] /= numeroLecturasCNYs;
    activacionesCNY[i] /= 2;
    debugPrint(activacionesCNY[i]);
    debugPrint('\t');
  }
  debugPrintln();

  debugPrintln("Activaciones Sharps");
  for (size_t i = 0; i < NUM_SHARPS; i++) {
    activacionesSharp[i] /= numeroLecturasSharps;
    activacionesSharp[i] *= 1.5;
    activacionesSharp[i] = constrain(activacionesSharp[i], 40, 70);
    debugPrint(activacionesSharp[i]);
    debugPrint('\t');
  }
  debugPrintln();

#if DEBUG
  delay(1000);
#endif
}

unsigned long ultimoRetroceso = -1;

unsigned long siguienteTiempoAvance = -1;

/// Literalmente solo buscar y matar
void estrategiaBasica(bool girarDerechaPorDefecto) {
  bool sharpIzq = smoothedSharps[SHARP_IZQ].get() > activacionesSharp[SHARP_IZQ];
  bool sharpCen = smoothedSharps[SHARP_CEN].get() > activacionesSharp[SHARP_CEN];
  bool sharpDer = smoothedSharps[SHARP_DER].get() > activacionesSharp[SHARP_DER];

  /// Último tiempo en milisegundos que empece a detectar algo en el sharp del centro
  static unsigned long ultimoTiempoDeteccionCentro = millis();
  /// Si la última vez que corrí detecté algo en el sharp del centro
  static bool ultimoDetectandoCentro = false;

  static bool avanzandoForzadamente = false;
  static unsigned long ultimoAvanceForzado = millis();
  if (millis() - ultimoAvanceForzado > TIEMPO_ESPERA_AVANCE_FORZADO_MS) {
    ultimoAvanceForzado = millis();
    avanzandoForzadamente = true;
  }
  if (avanzandoForzadamente) {
    if (millis() - ultimoAvanceForzado > TIEMPO_AVANCE_FORZADO_MS) {
      avanzandoForzadamente = false;
    }
    analogWrite(MOT_L_PWM, 255);
    analogWrite(MOT_R_PWM, 255);
    adelante();
  }

  if (sharpCen) {
    // Si acabo de detectar algo en el sharp del centro
    if (ultimoDetectandoCentro == false) {
      ultimoTiempoDeteccionCentro = millis();
    }
    if (millis() - ultimoTiempoDeteccionCentro > 300) {
      analogWrite(MOT_L_PWM, min((uint16_t)MOT_L_PWM_MAX + 50, 255));
      analogWrite(MOT_R_PWM, min((uint16_t)MOT_R_PWM_MAX + 50, 255));
    } else {
      analogWrite(MOT_L_PWM, min((uint16_t)MOT_L_PWM_MAX + 30, 255));
      analogWrite(MOT_R_PWM, min((uint16_t)MOT_R_PWM_MAX + 30, 255));
    }
    adelante();
  } else {
    analogWrite(MOT_L_PWM, MOT_L_PWM_MAX);
    analogWrite(MOT_R_PWM, MOT_R_PWM_MAX);
    if (girarDerechaPorDefecto) {
      if (sharpIzq) {
        izquierda();
      } else {
        derecha();
      }
    } else {
      if (sharpDer) {
        derecha();
      } else {
        izquierda();
      }
    }
  }

  ultimoDetectandoCentro = sharpCen;
}

void estrategiaPasitos() {
  bool sharpIzq = smoothedSharps[SHARP_IZQ].get() > activacionesSharp[SHARP_IZQ];
  bool sharpCen = smoothedSharps[SHARP_CEN].get() > activacionesSharp[SHARP_CEN];
  bool sharpDer = smoothedSharps[SHARP_DER].get() > activacionesSharp[SHARP_DER];
}

unsigned long comienzoRetroceso = millis();
bool retrocediendo = false;

void loop() {
  leerSharps();
  debugPrint(activacionesSharp[SHARP_IZQ]);
  debugPrint('\t');
  debugPrint(activacionesSharp[SHARP_CEN]);
  debugPrint('\t');
  debugPrintln(activacionesSharp[SHARP_DER]);

  leerCNY();
  debugPrint(lecturasCNY[CNY_IZQ]);
  debugPrint('\t');
  debugPrintln(lecturasCNY[CNY_DER]);

  bool cnyIzq = lecturasCNY[CNY_IZQ] <= activacionesCNY[CNY_IZQ];
  bool cnyDer = lecturasCNY[CNY_DER] <= activacionesCNY[CNY_DER];
  if (cnyIzq || cnyDer) {
    if (millis() - comienzoRetroceso <= TIEMPO_RETROCEDER_MS * 2) {
      comienzoRetroceso = millis() - TIEMPO_RETROCEDER_MS / 2;
    } else {
      comienzoRetroceso = millis();
    }
    retrocediendo = true;
  }

  if (retrocediendo) {
    if (millis() - comienzoRetroceso > TIEMPO_RETROCEDER_MS) {
      retrocediendo = false;
    }
    analogWrite(MOT_L_PWM, MOT_L_PWM_MAX);
    analogWrite(MOT_R_PWM, MOT_R_PWM_MAX);
    atras();
  } else {
    switch (estrategia) {
      case BASICA_DER:
        estrategiaBasica(false);
        break;
      case BASICA_IZQ:
        estrategiaBasica(true);
        break;
      case PASITOS:
        estrategiaBasica(true);
        break;
    }
  }

  bool sharpIzq = smoothedSharps[SHARP_IZQ].get() > activacionesSharp[SHARP_IZQ];
  bool sharpCen = smoothedSharps[SHARP_CEN].get() > activacionesSharp[SHARP_CEN];
  bool sharpDer = smoothedSharps[SHARP_DER].get() > activacionesSharp[SHARP_DER];

  cambiarLed(0, sharpIzq);
  cambiarLed(1, sharpCen);
  cambiarLed(2, sharpDer);
  // for (size_t i = 0; i < NUM_LEDS; i++) {
  //   cambiarLed(i, bitRead(smoothedSharps[SHARP_CEN].get() >> 1, i) == true);
  // }
#if DEBUG
  delay(100);
#endif
}

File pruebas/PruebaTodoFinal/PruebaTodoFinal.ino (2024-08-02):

#include "TimerOne.h"


#define BOTON_1 2
#define BOTON_2 3

#define LED_V 4
#define LED_R1 5
#define LED_R2 8


#define INIT 0
#define E1 1
#define E2 2
#define START 3
#define E3 4
#define E4 5
#define E5 6


int estadob1 = 0;
int estadob2 = 0;
int mseg = 0;
int estadoLogica = 0;

#define ESPERA 0
#define CONFIRMACION 1
#define LIBERACION 2

#define TIEMPO_antiReboteBoton1 15
int estadoantiReboteBoton1 = 0;
int mSegantiReboteBoton1 = 0;
int flagBoton1 = 0;

#define TIEMPO_antiReboteBoton2 15
int estadoantiReboteBoton2 = 0;
int mSegantiReboteBoton2 = 0;
int flagBoton2 = 0;

int flagEstrategia = 0;

#define CNY1 A6
#define CNY2 A4
int valorCNY1 = 0;
int valorCNY2 = 0;

//MOTORES y SHARPS
constexpr uint8_t MOT_L_A = 7;
constexpr uint8_t MOT_L_B = 6;
constexpr uint8_t MOT_L_PWM = 11;
constexpr uint8_t MOT_R_A = 9;
constexpr uint8_t MOT_R_B = 12;
constexpr uint8_t MOT_R_PWM = 10;

constexpr uint8_t PINES_SHARPS[3] = { A7, A5, A3 };
constexpr size_t NUM_SHARPS = sizeof(PINES_SHARPS) / sizeof(PINES_SHARPS[0]);

constexpr float VOLTAJE_MAX_ADC = 5.0;
constexpr uint8_t BITS_ADC = 10;
constexpr uint16_t VALOR_MAX_ADC = pow(2, BITS_ADC);

void adelante() {
  Serial.println("Adelante");
  digitalWrite(MOT_L_A, HIGH);
  digitalWrite(MOT_L_B, LOW);
  digitalWrite(MOT_R_A, HIGH);
  digitalWrite(MOT_R_B, LOW);
}

void atras() {
  Serial.println("Atras");
  digitalWrite(MOT_L_A, LOW);
  digitalWrite(MOT_L_B, HIGH);
  digitalWrite(MOT_R_A, LOW);
  digitalWrite(MOT_R_B, HIGH);
}

void izquierda() {
  Serial.println("Izquierda");
  digitalWrite(MOT_L_A, HIGH);
  digitalWrite(MOT_L_B, LOW);
  digitalWrite(MOT_R_A, LOW);
  digitalWrite(MOT_R_B, HIGH);
}

void izquierda2() {
  Serial.println("Izquierda2");
  digitalWrite(MOT_L_A, LOW);
  digitalWrite(MOT_L_B, HIGH);
  digitalWrite(MOT_R_A, LOW);
  digitalWrite(MOT_R_B, LOW);
}

void derecha() {
  Serial.println("Derecha");
  digitalWrite(MOT_L_A, LOW);
  digitalWrite(MOT_L_B, HIGH);
  digitalWrite(MOT_R_A, HIGH);
  digitalWrite(MOT_R_B, LOW);
}

void derecha2() {
  Serial.println("Derecha2");
  digitalWrite(MOT_L_A, LOW);
  digitalWrite(MOT_L_B, LOW);
  digitalWrite(MOT_R_A, LOW);
  digitalWrite(MOT_R_B, HIGH);
}

void parada() {
  Serial.println("Parada");
  digitalWrite(MOT_L_A, LOW);
  digitalWrite(MOT_L_B, LOW);
  digitalWrite(MOT_R_A, LOW);
  digitalWrite(MOT_R_B, LOW);
}

void frenar() {
  Serial.println("Frenado");
  digitalWrite(MOT_L_A, HIGH);
  digitalWrite(MOT_L_B, HIGH);
  digitalWrite(MOT_R_A, HIGH);
  digitalWrite(MOT_R_B, HIGH);
}

void setupMotores() {
  Serial.println("Inicializando pines de los motores...");
  Serial.println("Pin motor izq adelante");
  pinMode(MOT_L_A, OUTPUT);
  Serial.println("Pin motor izq atras");
  pinMode(MOT_L_B, OUTPUT);
  Serial.println("Pin motor izq velocidad (PWM)");
  pinMode(MOT_L_PWM, OUTPUT);
  Serial.println("Pin motor der adelante");
  pinMode(MOT_R_A, OUTPUT);
  Serial.println("Pin motor der atras");
  pinMode(MOT_R_B, OUTPUT);
  Serial.println("Pin motor der velocidad (PWM)");
  pinMode(MOT_R_PWM, OUTPUT);
  Serial.println("Pines de los motores inicializados!");

  Serial.println("Poniendo dirección inicial en los motores");
  parada();
  Serial.println("Puesta la dirección inicial en los motores!");

  Serial.println("Poniendo velocidad en los motores");
  analogWrite(MOT_L_PWM, 255);
  analogWrite(MOT_R_PWM, 255);
  Serial.println("Velocidad de los motores establecidas!");
}

uint8_t distanciasSharps[NUM_SHARPS];

uint8_t* leerSharps() {
  for (int i = 0; i < NUM_SHARPS; i++) {
    distanciasSharps[i] = (uint8_t)round(17569.7 * pow(analogRead(PINES_SHARPS[i]), -1.2062));
    Serial.print("Sharp ");
    Serial.print(i + 1);
    Serial.print(':');
    Serial.print(distanciasSharps[i]);
    Serial.print('\t');
  }
  Serial.println();
  return distanciasSharps;
}

void setupSharps() {
  Serial.println("Inicializando pines de los sharps...");
  for (int i = 0; i < NUM_SHARPS; i++) {
    Serial.print("Sensor distancia sharp ");
    pinMode(PINES_SHARPS[i], INPUT);
    Serial.println(i + 1);
  }
  Serial.println("Pines de los sharps inicializados!");
}

void setup() {
  pinMode(BOTON_1, INPUT_PULLUP);
  pinMode(BOTON_2, INPUT);

  pinMode(LED_V, OUTPUT);
  pinMode(LED_R1, OUTPUT);
  pinMode(LED_R2, OUTPUT);

  Timer1.initialize(1000);
  Timer1.attachInterrupt(callBack);

  Serial.begin(115200);

  setupMotores();

  setupSharps();

  Serial.println("Comenzando loop en 2 segundos...");
  delay(2000);
}

void loop() {
  antiReboteBoton1();
  antiReboteBoton2();
  maquinaBotones();
}



void callBack() {
  mseg = mseg + 1;
  mSegantiReboteBoton1 += 1;
  mSegantiReboteBoton2 += 1;
}

void maquinaBotones() {
  switch (estadob1) {
    case INIT:
      digitalWrite(LED_V, LOW);
      digitalWrite(LED_R1, HIGH);
      digitalWrite(LED_R2, LOW);
      estadob1 = E1;
      break;

    case E1:

      if (flagBoton1 == 1) {
        mseg = 0;
        estadob1 = E2;
        flagBoton1 = 0;
        digitalWrite(LED_R2, HIGH);
      }
      if (flagBoton2 == 1) {
        estadob1 = E3;
        flagBoton2 = 0;
        digitalWrite(LED_R2, HIGH);
      }
      break;

    case E2:

      if (mseg >= 3000) {
        digitalWrite(LED_R1, LOW);
        digitalWrite(LED_R2, LOW);
        mseg = 0;
        estadob1 = START;
      }
      break;

    case E3:

      digitalWrite(LED_R1, LOW);
      digitalWrite(LED_R2, HIGH);
      flagEstrategia = 1;
      if (flagBoton2 == 1) {
        digitalWrite(LED_R1, HIGH);
        digitalWrite(LED_R2, LOW);
        estadob1 = E4;
        flagBoton2 = 0;
      }

      if (flagBoton1 == 1) {
        mseg = 0;
        estadob1 = E2;
        flagBoton1 = 0;
        digitalWrite(LED_R2, HIGH);
      }

      break;

    case E4:

      digitalWrite(LED_R1, HIGH);
      digitalWrite(LED_R2, LOW);
      flagEstrategia = 0;
      if (flagBoton2 == 1) {
        estadob1 = E3;
        flagBoton2 = 0;
      }
      if (flagBoton1 == 1) {
        mseg = 0;
        estadob1 = E2;
        flagBoton1 = 0;
        digitalWrite(LED_R2, HIGH);
      }

      break;
    case START:
      digitalWrite(LED_V, HIGH);
      leerSharps();
      valorCNY1 = analogRead(CNY1);
      valorCNY2 = analogRead(CNY2);
      Serial.println(valorCNY1);
      Serial.println(valorCNY2);

      maquinaLogica();


      break;
  }
}
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

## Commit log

2024-05-31 Agregar el símbolo electrónico del inductor al README
2024-06-19 Agregar prueba de los sensores
2024-06-19 Arreglar error boludo\ me olvide de cambiar la resolucion del ADC :/
    [sensores.ino]
2024-07-05 Agregar prueba de motores
2024-07-05 Arreglar prueba de sensores
    [sensores.ino]
2024-07-06 Prueba motores con pines
2024-07-11 Arreglar archivos subidos incorrectamente
    [motores.ino]
2024-07-11 Agregar prueba inicial de motores y sensores
2024-08-02 Terminar (por favor) el código de Bobina v1
2024-08-03 Implementar selección de dirección preferida
2024-09-06 Convertir tiempo que retrocede a una variable, cambiar el método de suavizamiento y hacer que use más lecturas de los sharp
2024-09-07 Arreglar descripciones y comentarios
    De la constexpr TIEMPO_RETROCEDER_MS
    [bobina_v1.ino]
2024-09-07 Bajar velocidades máximas
    Las bajé porque si no detectaba al oponente o se caía
2024-09-07 Bajar lecturas de los sharps para el suavizado
    Noté que a veces no detectaba al oponente porque lo veía muy poco tiempo y seguía girando.
    Por eso baje las lecturas de los sharps de 5 a 3.
2024-09-07 Agregar código de avance automático
    Es parecido a lo que hace el mini sumo de Prieto para evitar que se pare la pelea.
    Además le gustó la idea. :smiley:
2024-09-07 Cambiar y arreglar tiempos
    Cambié los de retroceso y avance forzado, además de agregar las partes que faltaban
    [bobina_v1.ino]
2024-09-07 Cambiar valores para los sharps
    Cambié la distancia de activación, bajé la frecuencia y baje las lecturas utilizadas para el promedio
2024-09-07 Cambiar valores para los CNYs
2024-09-07 Hacer que vaya a velocidad máxima si tiene algo adelante
    ...y no detectó blanco
2024-09-07 Código boludo de laverinto
    No se, lo hice porque estaba aburrido y bueno :P
2024-09-07 Cambiar el orden de los nombres en el README.md
    Bobina es el nombre más usado, así que lo moví para que este primero
2024-09-11 PRUEBA LEDS
2024-09-13 Agregar libreria de SharpIR
2024-09-13 Sacar delay y reducir lecturas por segundo de los sharp
2024-09-14 Hacer que siga girando en esa dirección cuando ve algo
2024-11-06 Implementar selección de estrategia y arreglar errores de compilación
    [bobina_v1.1.ino]
2024-11-06 Cambiar velocidad de los motores y arreglar advertencia de compilación
    [bobina_v1.1.ino]
2024-11-06 Cambiar constantes relacionadas a la lectura de sharps
2024-11-06 Cambiar visualización de selección de estrategia
2024-11-06 Agregar avance forzado y que retroceda por menos tiempo si acaba de retroceder
2025-01-06 Last upload
    [First Bobina.stl, First bobina assembly.stl, Last Bobina (for iron base).stl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]
2025-09-01 PLACA V1
    [V1.kicad_pcb, V1.kicad_sch]
2025-09-02 placa v2
    [V2.kicad_pcb, V2.kicad_sch]
2025-09-02 placa v2 con xt30
    [V2.kicad_pcb, V2.kicad_sch]
